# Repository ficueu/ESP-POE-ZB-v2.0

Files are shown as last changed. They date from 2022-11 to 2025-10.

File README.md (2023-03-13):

# ESP-POE-ZB-v2.0
ESP32 POE: ZigBee + BLE gateway

Features:
* ESPHome compatible,
* ESP32-S (with U.FL connector) used as BLE receiver, main gateway controller,
* Ebyte E72-2G4M20S1E (CC2652p with U.FL connector) as ZigBee coordinator,
* POE 802.3af/802.3at (36-57 VDC) with LAN8720,
* passive POE 12-57V (experimental, need to solder jumper on PCB),
* USBC for flashing, based on CH340C (can be used for powering),
* power connector: 10-57 VDC (abs max 70V - needs to replace capacitor),
* external connectors: 5xGPIO (3 of them internal pulled up, for SCL, SDA, 1Wire), 3.3V, 5V, GND,
* internal connectors: SCL, SDA, 3.3V, GND (SCL and SDA shared with external connector; more gpio available without zigbee module),
* support for RS485/MODBUS (need to add ISL83485 or similar - note: RS485 disable I2C and 1Wire),
* support for CAN (canbus) (need to add 3V3 CAN transceiver),
* BUS (input/POE) voltage monitoring,
* LEDs: power (green) and status (amber).

### DO NOT POWER ON MODULE WITHOUT ANTENNAS

Example ESPHome yaml file: https://github.com/ficueu/ESP-POE-ZB-v2.0/blob/main/esp-poe-zb-v20.yaml
(outdated config yaml: https://github.com/ficueu/ESP-POE-ZB-v2.0/blob/main/esp-poe-zb-v2.yaml)

Enclosure STL files: https://github.com/ficueu/ESP-POE-ZB-v2.0/tree/main/enclosure

Pinout (top screw terminal connector):
```
1: RS485 B or GPIO13
2: RS485 A or GPIO14
3: CAN HIGH or GPIO15
4: CAN LOW or GPIO16
5: GPIO32 or GPIO33
6: +5V
7: +3.3V
8: GND
```

Pinout (bottom screw terminal connector):
```
1: VCC (INPUT: 10-57 VDC)
2: GND
```

Pinout (ESP32 side):
```
i2c:
  sda: 14
  scl: 13
  id: i2cbus

dallas:
  - pin: 16

uart:
  id: modbus
  tx_pin: 14
  rx_pin: 13
  baud_rate: 115200
  stop_bits: 1

modbus:
  flow_control_pin: 16  //it can be changed to GPIO33 by jumper on PCB)
  id: modbus1
  
canbus:
  - platform: esp32_can
    tx_pin: GPIO15
    rx_pin: GPIO16
    can_id: 1
    bit_rate: 50kbps

status_led:
  pin:
    number: 2
    inverted: true

ethernet:
  type: LAN8720
  mdc_pin: GPIO23
  mdio_pin: GPIO18
  clk_mode: GPIO17_OUT
  phy_addr: 1
  power_pin: GPIO12
  
uart: //for ZigBee
  - id: uart_bus
    rx_pin: GPIO4
    tx_pin: GPIO5
    baud_rate: 115200

sensor:
  - platform: adc
    attenuation: 11dB
    filters:
      - multiply: 20.6
    pin: GPIO35
    name: "Bus Voltage"
    update_interval: 60s
```

ZigBee2MQTT config:

```
serial:
  port: tcp://YOUR-IP:1234
```

Updating ZigBee firmware:
1. Read https://www.zigbee2mqtt.io/guide/adapters/flashing/flashing_via_cc2538-bsl.html
2. Prepare cc2538-bsl tool.
3. Turn on "Zigbee BSL" on your EespHome device integration.
4. Wait 10s.
5. Run cc2538-bsl: 
```
python cc2538-bsl.py -b 115200 -p socket://IP-OF-DEVICE:1234 -evw FILENAME.HEX"
```
eg (for IP: 192.168.0.126 and filename CC1352P2_CC2652P_other_coordinator_20220219.hex):
```
python cc2538-bsl.py -b 115200 -p socket://192.168.0.126:1234 -evw CC1352P2_CC2652P_other_coordinator_20220219.hex
```
6. Wait until firmware was upload and verified successfully, it can take few minutes.

Successfully flashing process:
```
Opening port socket://192.168.0.126:1234, baud 115200
Reading data from CC1352P2_CC2652P_other_coordinator_20220219.hex
Your firmware looks like an Intel Hex file
Connecting to target...
CC1350 PG2.0 (7x7mm): 352KB Flash, 20KB SRAM, CCFG.BL_CONFIG at 0x00057FD8
Primary IEEE Address: XX:XXXX:XX:XX:XX:XX:XX
    Performing mass erase
Erasing all main bank flash sectors
    Erase done
Writing 360448 bytes starting at address 0x00000000
Write 104 bytes at 0x00057F988
    Write done
Verifying by comparing CRC32 calculations.
    Verified (match: 0x9f4c5825)
```

If error is occured "ERROR: Timeout waiting for ACK/NACK after 'Send data (0x24)'" back to pint 3. and try again.

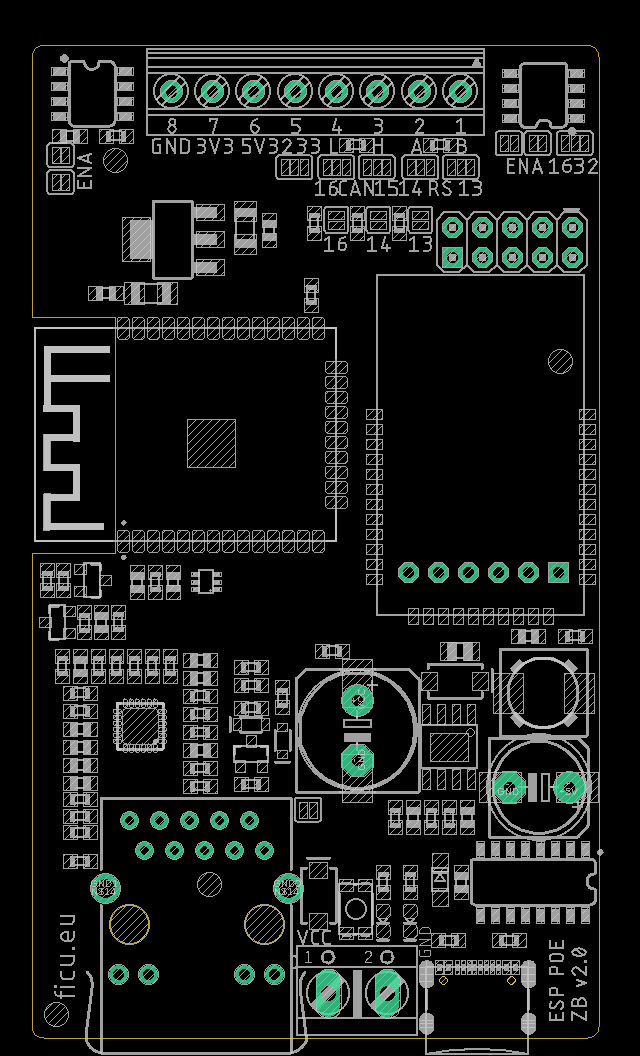
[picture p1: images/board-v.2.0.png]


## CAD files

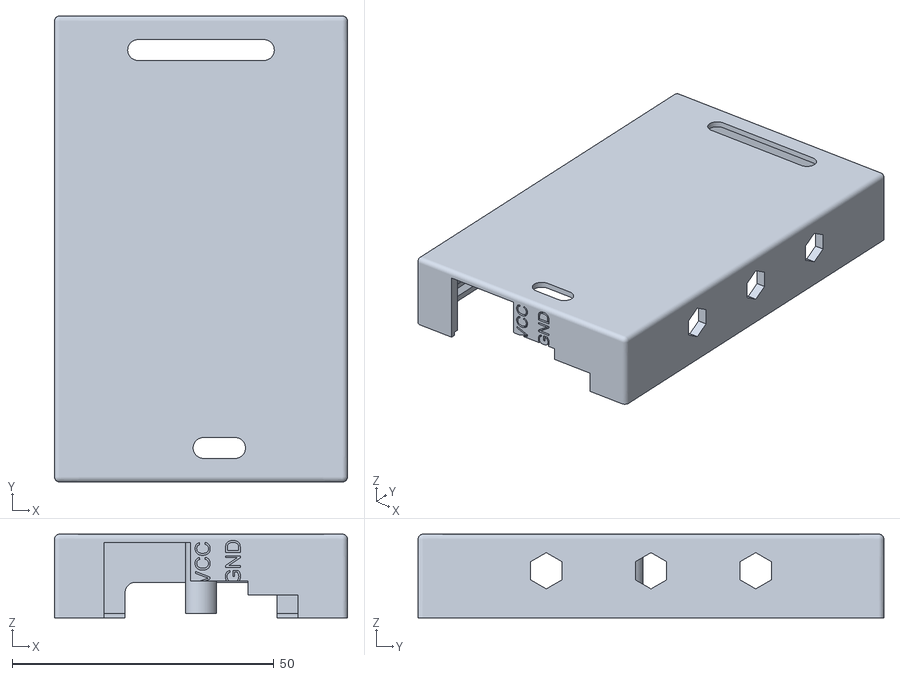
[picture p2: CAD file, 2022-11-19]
enclosure/obudowa-gorna-v2.0.stl
56.0 x 89.0 x 16.0

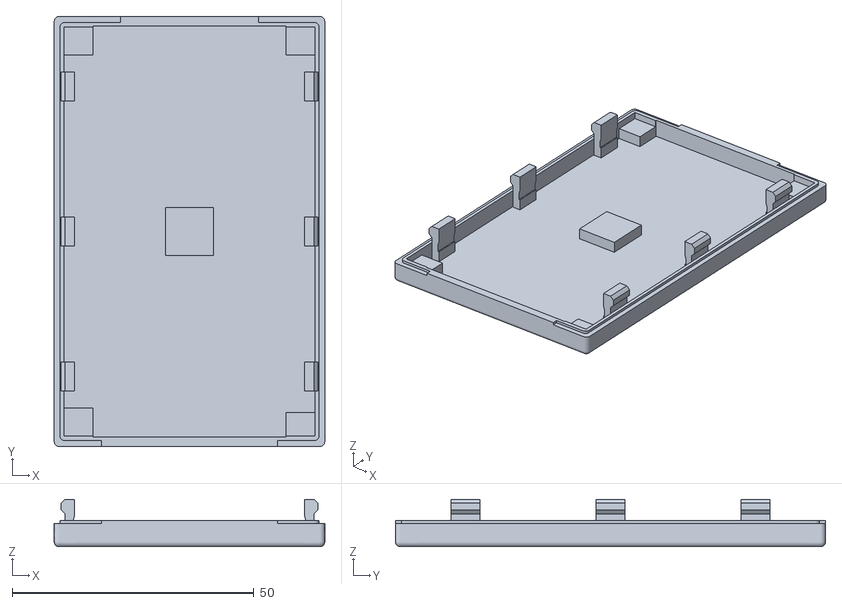
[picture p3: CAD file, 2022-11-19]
enclosure/obudowa-dolna-v2.0.stl
56.0 x 89.0 x 9.80

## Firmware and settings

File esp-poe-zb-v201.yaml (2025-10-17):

substitutions:
  name: esp-poe-zb-v201
  friendly_name: "ESP32 PoE ZigBee Gateway v2.01"

esphome:
  name: "${name}"
  friendly_name: "${friendly_name}"

  #name_add_mac_suffix: true

  project:
    name: "ficueu.esp-poe-zb-v201"
    version: "2.01"

  on_boot:
    priority: 800.0
    then:
      - output.turn_off: zbBSL
      - output.turn_off: zbRST
      
esp32:
  board: esp32dev
  framework:
    type: esp-idf

dashboard_import:
  package_import_url: github://ficueu/ESP-POE-ZB-v2.0/esp-poe-zb-v201.yaml@main
  import_full_config: true

logger:

api:
  reboot_timeout: 0s

debug:
  update_interval: 60s

ota:
  - platform: esphome

status_led:
  pin:
    number: 2
    inverted: true
    
ethernet:
  type: LAN8720
  mdc_pin: GPIO23
  mdio_pin: GPIO18
  clk:
    mode: CLK_OUT
    pin: GPIO17
  phy_addr: 1
  power_pin: GPIO12
  
web_server:
  port: 80
  version: 1

sensor:
  - platform: uptime
    name: GW uptime
  - platform: debug
    free:
      name: "Heap Free" 

  - platform: adc
    attenuation: 11dB
    filters:
      - multiply: 20.6
    pin: GPIO35
    name: "Bus Voltage"
    update_interval: 60s
   
external_components:
  - source: github://oxan/esphome-stream-server


button:
  - platform: restart
    name: "Gateway restart"
    id: gwrst

  - platform: template
    name: "ZigBee force update"
    on_press:
      - switch.turn_on: disrst
      - output.turn_on: zbBSL
      - delay: 100ms
      - output.turn_on: zbRST
      - delay: 100ms
      - output.turn_off: zbRST
      - delay: 100ms
      - output.turn_off: zbBSL
      - delay: 100ms
      - logger.log: "Done. Please update FW now."

  - platform: output
    name: "ZigBee reset"
    output: zbRST
    id: btnzbRST
    duration: 1s
    on_press: 
      then:
        - logger.log: "Zigbee module reset."

output:
  - platform: gpio
    pin: 32
    id: zbRST
    inverted: yes
  - platform: gpio
    pin: 33
    id: zbBSL
    inverted: yes

number:
  - platform: template
    min_value:  0
    max_value: 2
    step: 1
    initial_value: 0
    id: streamcnt
    optimistic: True
    on_value:
      then:
        - if:
            condition:
              number.in_range:
                id: streamcnt
                above: 1.1
            then:
              - if:
                  condition:
                    - switch.is_off: disrst
                  then:
                    - button.press: gwrst

binary_sensor:
  - platform: stream_server
    connected:
      name: "ZB client connected"
      on_press:
        then:
          - if:
              condition:
                - switch.is_off: disrst
              then:
                - button.press: btnzbRST
      on_release:
        then:
          - number.increment: streamcnt
    stream_server: zigbee_stream

switch:
  - platform: template
    name: "Disable auto reset"
    restore_mode: RESTORE_DEFAULT_OFF
    optimistic: True
    id: disrst
 
stream_server:
  id: zigbee_stream
  uart_id: ZIGBEE
  port: 1234
    
#UART Settings
uart:
  - id: ZIGBEE
    rx_pin: GPIO4
    tx_pin: GPIO5
    baud_rate: 115200    

esp32_ble_tracker:
  scan_parameters:
    interval: 1100ms
    window: 1100ms

bluetooth_proxy:
  active: true
